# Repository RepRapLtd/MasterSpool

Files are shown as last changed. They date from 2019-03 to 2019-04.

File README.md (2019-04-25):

# MasterSpool

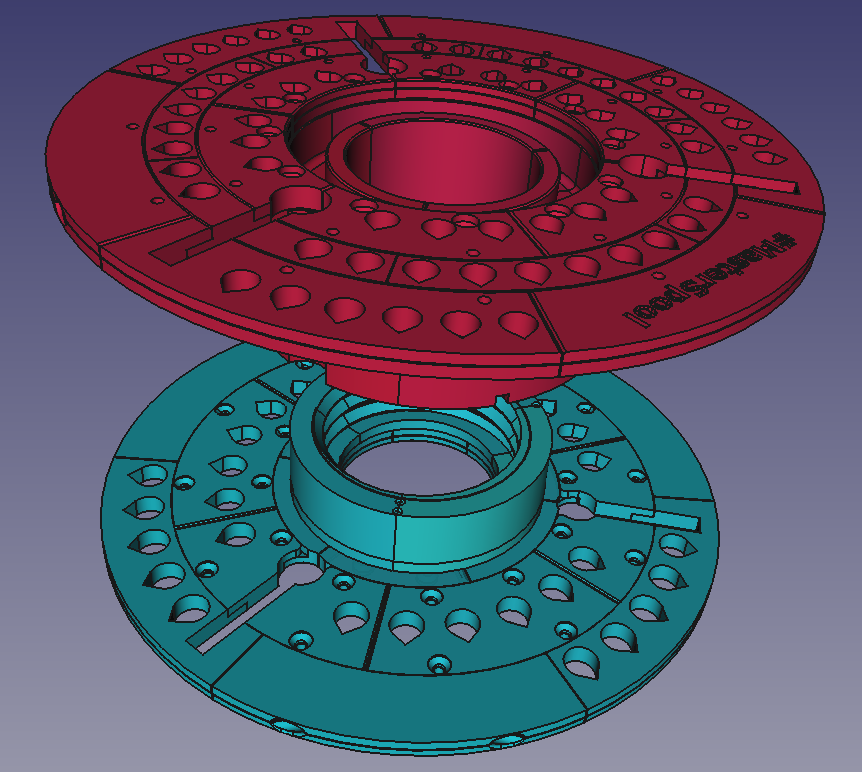
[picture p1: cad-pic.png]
CAD design


A variant of @RichRap's #MasterSpool (https://richrap.blogspot.com/2018/01/masterspool-proposed-standard-for-3d.html) universal FFF filament spool holder designed to be printed in parts on a small-bed machine such as RepRap Fisher (https://reprapltd.com/shop/reprap-fisher-delta-3d-printer/).

Each STL in the STLs directory has a file name that includes the number off that you need to print for one spool.

This needs 27 x (12mm M3) countersunk screws and 48 x (6mm M3) countersunk screws to hold it together.  The screws self-tap into holes in the design.

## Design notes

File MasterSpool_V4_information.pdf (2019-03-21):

## #MasterSpool – V4.0

The two part reusable 3D Printing spool for refill filament coils. | Version 4.0 – February 14th 2018

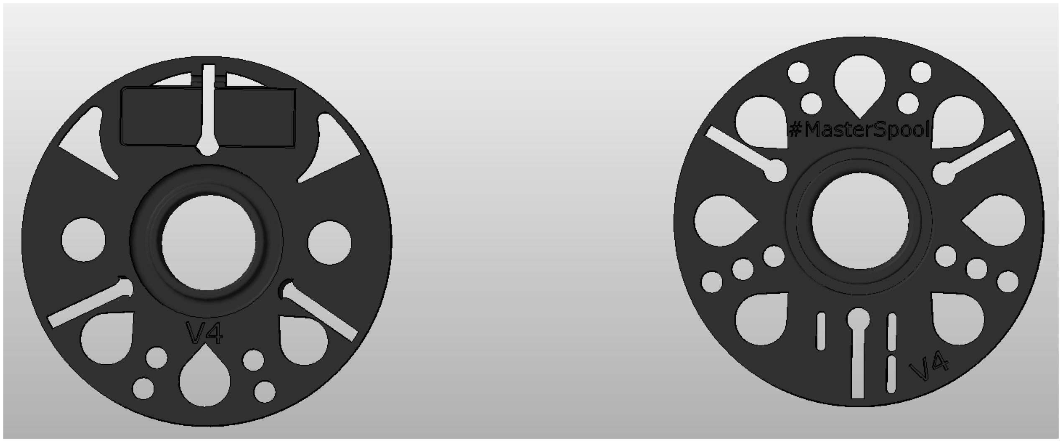
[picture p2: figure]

Significant dimensions of the MasterSpool refill system.

- Designed to use 1.75mm or 2.85mm filament (3.0mm also compatible).
- Outer MasterSpool diameter is 198mm Max.
- Width of the outer spool is 5.6mm on each side. ( to allow bearing type spool mounts)
- Inner ring diameter for the filament coil is 102mm
- Three channels around the inner ring at 120 degrees – for tie-wraps / zip-ties / straps etc.
- Recommended width of the filament coil is 46.7mm (+/- 0.5mm)
- Inner mounting hole is 52.5mm diameter (to fit standard 50mm/52mm spool holders)

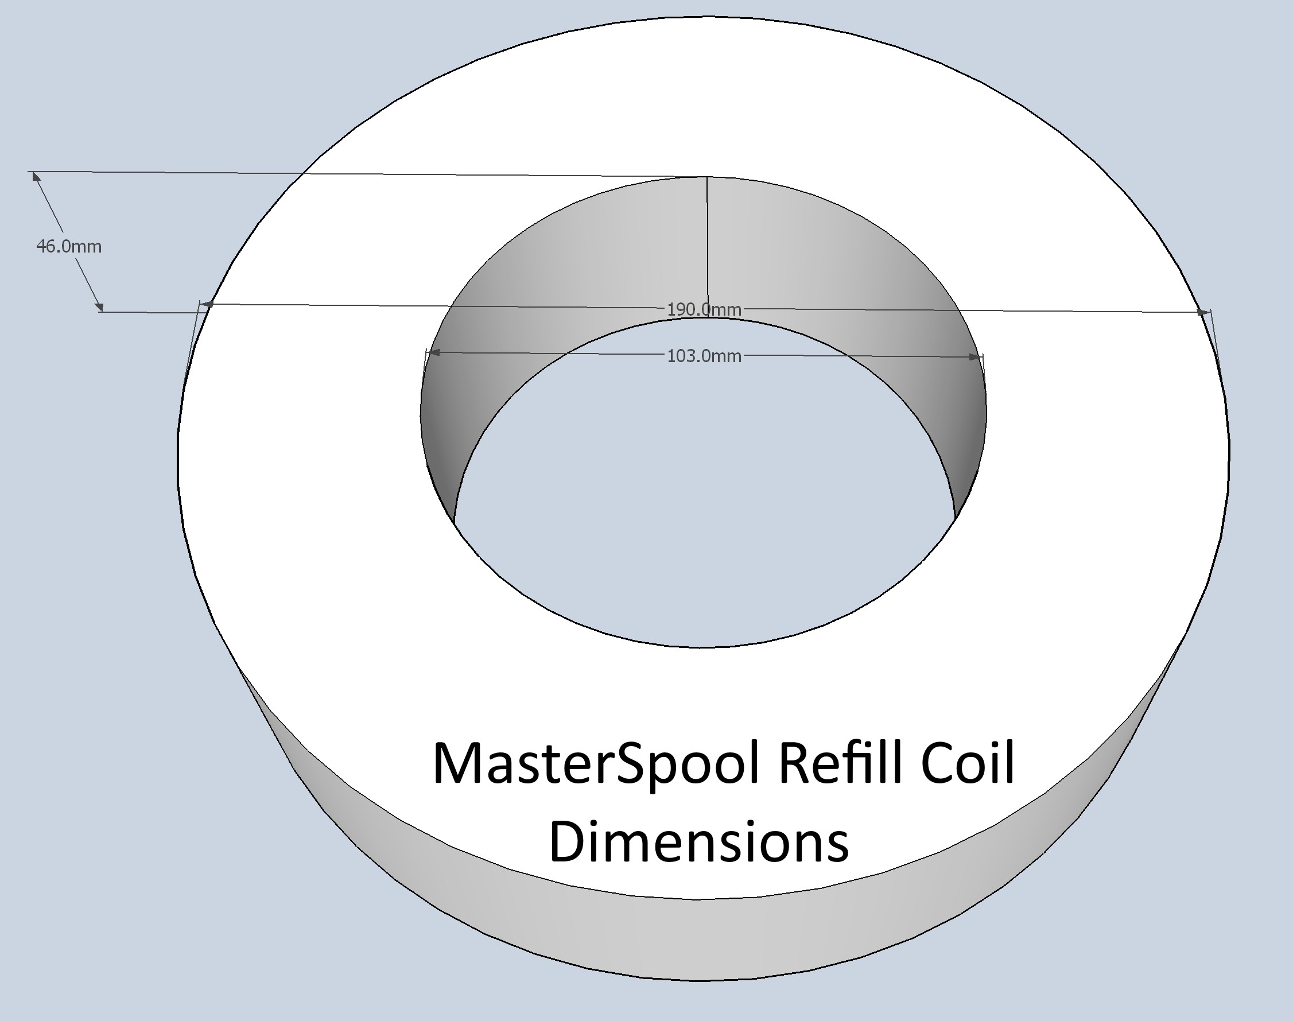
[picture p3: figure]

Suggested dimensions for the refill coil to use the MasterSpool holding system.

- Inner refill coil diameter 103mm +/- 1.0mm
- Width of refill coil 46mm +/- 0.5mm
- Outer refill coil diameter –
- No minimum dimension (depends on required refill coil weight / material type).
- Maximum dimension 190mm Max (<185mm recommended).
- Start of filament coil end to be ideally positioned half way between two tie-wrap points.
- Recommended tie-wraps / zip-ties or other strap from 2.4mm to 6.0mm wide – ideally a reusable tie-wrap is good for allowing users to remove the coil at any time.
- Ideally vacuum sealed for shipping to user.

Please feel free to design your own MasterSpools or compatible spool mounts for 3D printers, dry boxes, or whatever else you need.

MasterSpool is designed for and with the global 3D printing community. | @RichRap3D

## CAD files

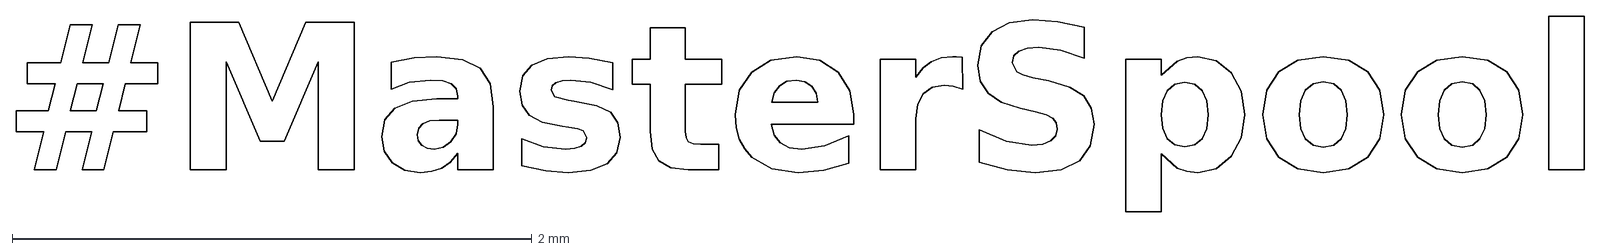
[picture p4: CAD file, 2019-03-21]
masterspool.dxf
6.04 x 0.753 mm

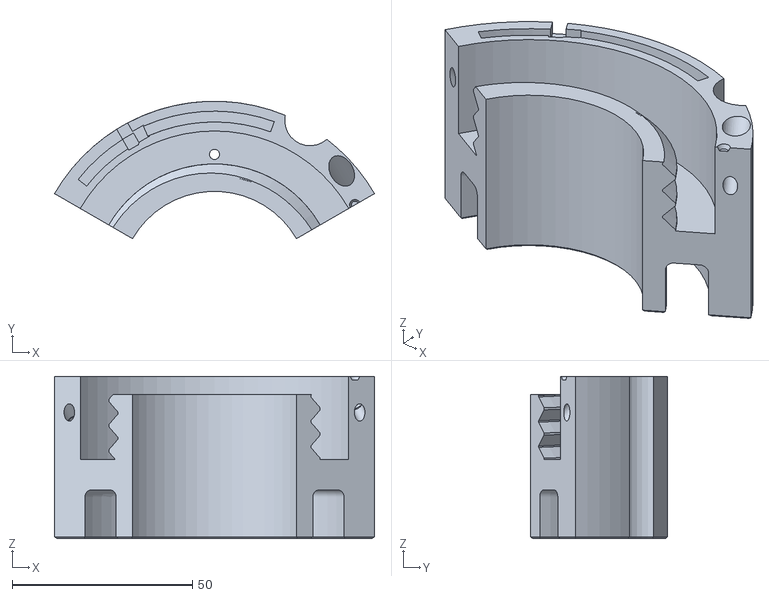
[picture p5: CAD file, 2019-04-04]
STLs/b-hub-a-1off.stl
88.8 x 38.1 x 45.0

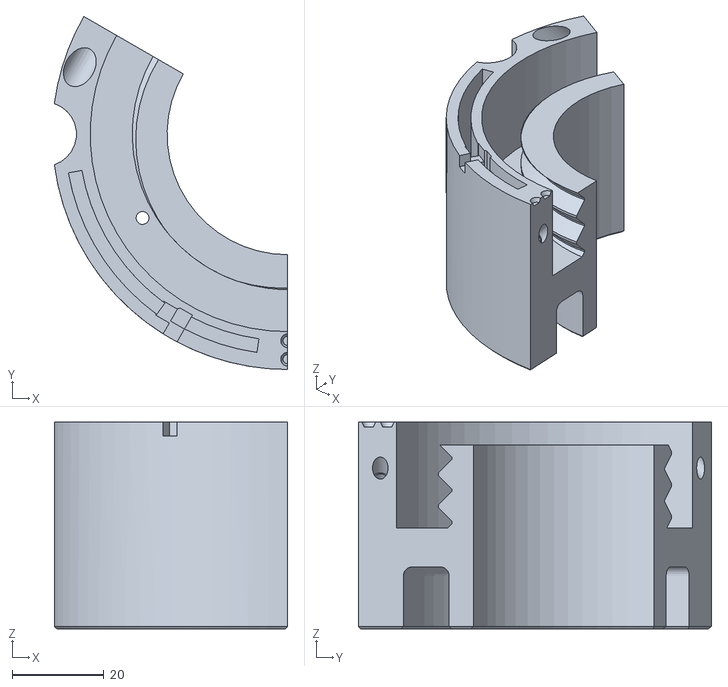
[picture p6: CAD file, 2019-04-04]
STLs/b-hub-b-1off.stl
50.8 x 76.9 x 45.0

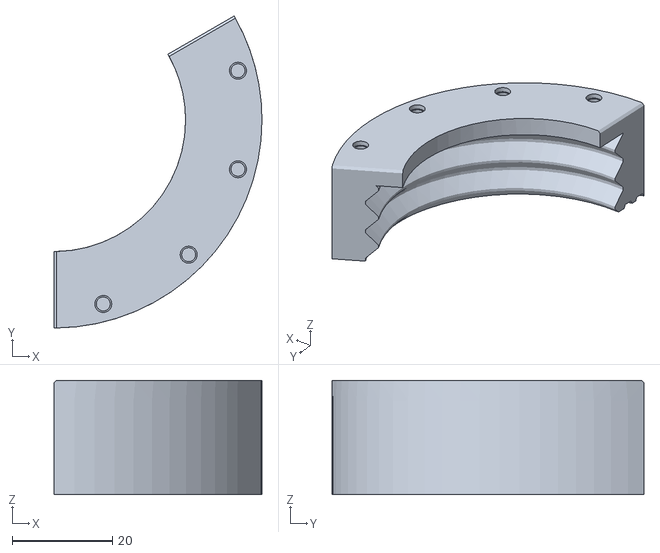
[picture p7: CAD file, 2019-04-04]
STLs/t-hub-a-1off.stl
41.5 x 62.2 x 22.8

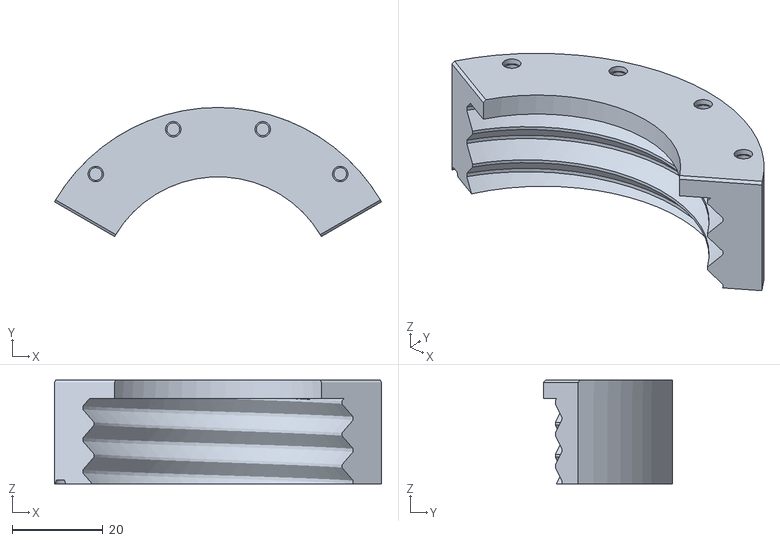
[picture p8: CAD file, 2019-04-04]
STLs/t-hub-c-1off.stl
71.9 x 28.4 x 22.8

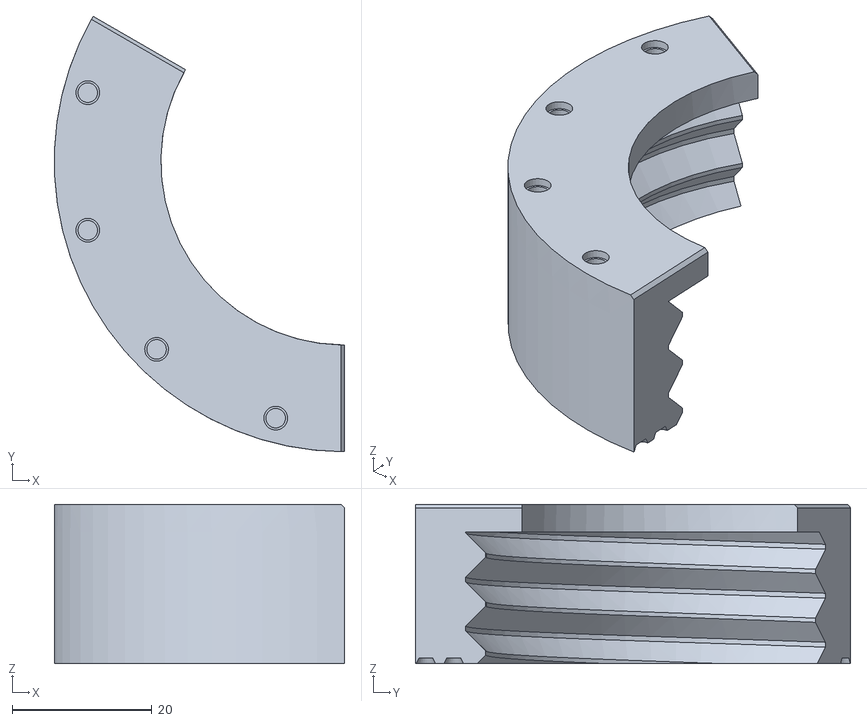
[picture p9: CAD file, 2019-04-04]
STLs/t-hub-b-1off.stl
41.5 x 62.2 x 22.8

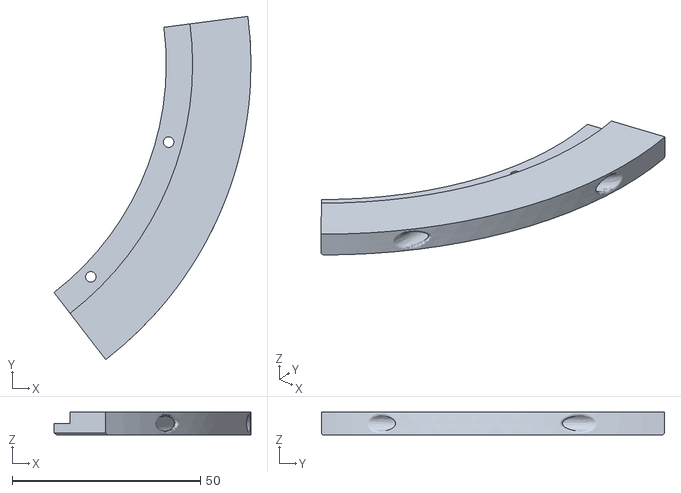
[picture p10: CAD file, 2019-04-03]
STLs/b-outer-tube-2off.stl
52.3 x 91.2 x 6.00

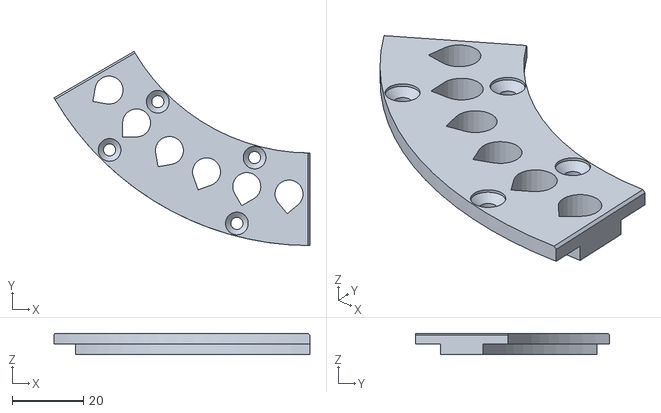
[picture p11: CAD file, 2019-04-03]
STLs/b-mid-3off.stl
72.0 x 54.6 x 6.00

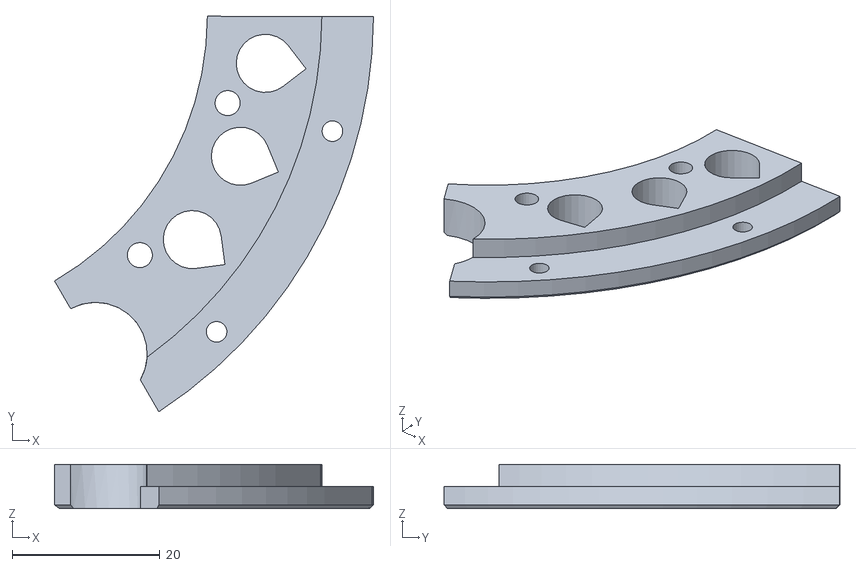
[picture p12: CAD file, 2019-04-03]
STLs/b-inner-l-3off.stl
43.2 x 53.6 x 6.00

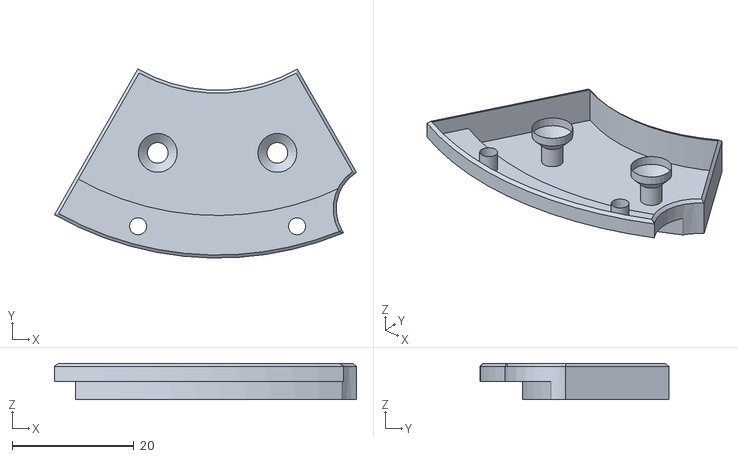
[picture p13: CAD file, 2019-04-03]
STLs/t-inner-l-3off.stl
49.7 x 31.1 x 6.00

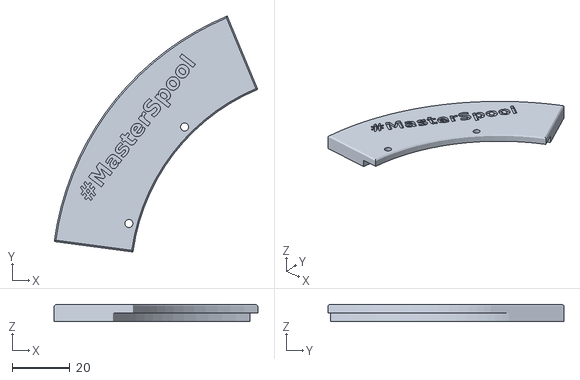
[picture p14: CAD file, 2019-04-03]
STLs/t-outer-master-1off.stl
70.7 x 82.0 x 6.00

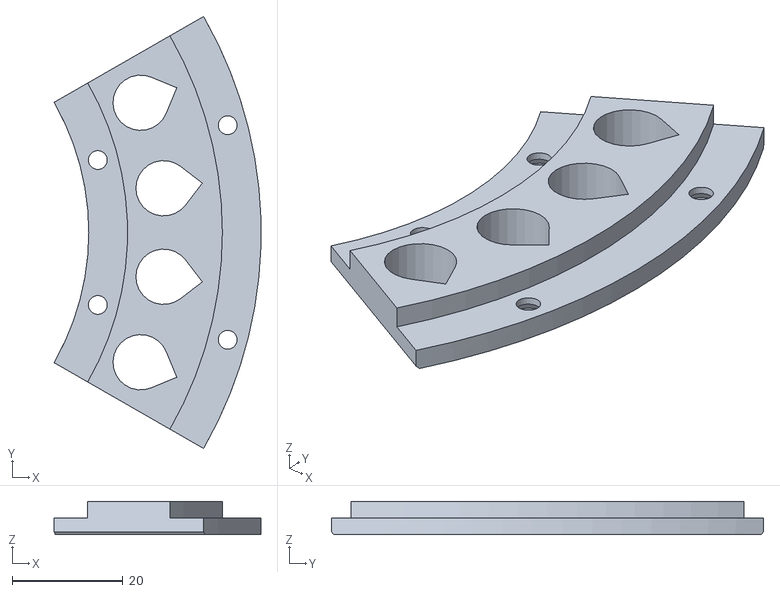
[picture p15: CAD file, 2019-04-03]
STLs/t-mid-3off.stl
37.3 x 77.9 x 6.00

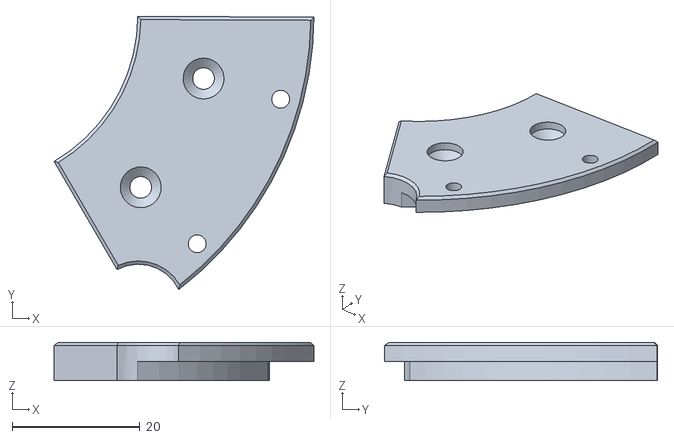
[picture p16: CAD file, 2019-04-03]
STLs/t-inner-r-3off.stl
40.7 x 42.8 x 6.00

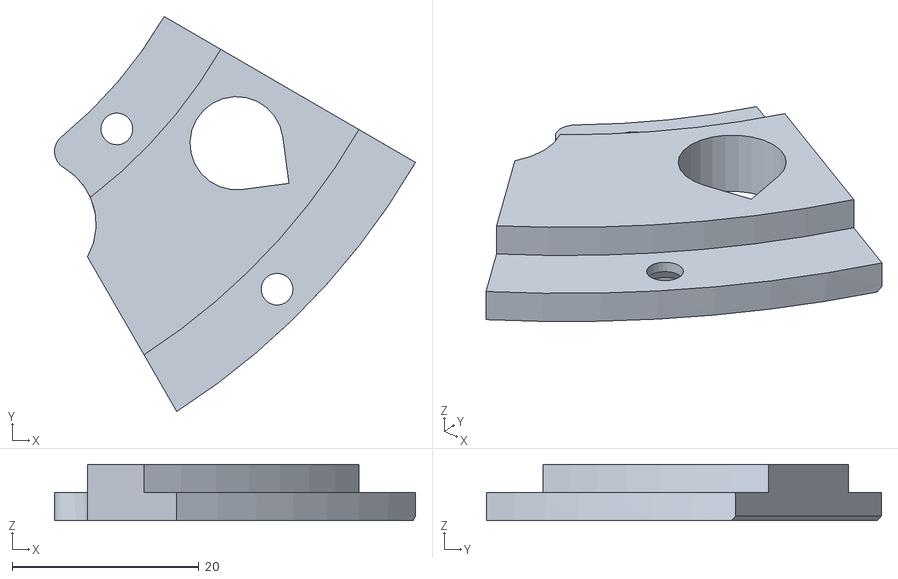
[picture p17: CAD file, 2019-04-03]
STLs/t-mid-slot-r-3off.stl
38.6 x 42.3 x 6.00

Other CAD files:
STLs/b-hub-c-1off.stl
STLs/b-mid-l-3off.stl
STLs/b-outer-slot-3off.stl
STLs/b-mid-r-3off.stl
Legacy/MasterSpool_V4_Feb14th_2018_RichRap_RTP_Master.FCStd
Legacy/MasterSpool_V4_Feb14th_2018_RichRap_RTP_Master1.FCStd
Legacy/masterspool-hash.fcstd
STLs/b-inner-r-3off.stl
STLs/b-outer-master-1off.stl
STLs/t-mid-slot-l-3off.stl
STLs/t-outer-slot-3off.stl
STLs/t-outer-tube-2off.stl

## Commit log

2019-03-22 First full design.
    [binding-tab-10-off.stl, binding-tab-5-off.stl, bottom-hub.stl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]
2019-03-28 New Masterspool design. W.I.P.
    [inner-sector.stl, mid-sector.g, mid-sector.stl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]
2019-03-29 Final (?) design of the base
    [MasterSpool_V4_Feb14th_2018_RichRap_RTP_Master.FCStd, MasterSpool_V4_Feb14th_2018_RichRap_RTP_Master1.FCStd, binding-tab-10-off.stl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]
2019-04-03 Final (?) Masterspool for printing on small machines.
    [b-hub-1.stl, b-hub-2.stl, b-hub-3.stl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]
2019-04-04 First fully-built version. Landing and lock screw taps added.
    [b-hub-1.stl, b-hub-2.stl, b-hub-3.stl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]
2019-04-25 Name tidying.
    [b-hub-a-1off.stl, b-hub-b-1off.stl, b-hub-c-1off.stl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]
2019-04-25 Added bit about number of STLs to print.
